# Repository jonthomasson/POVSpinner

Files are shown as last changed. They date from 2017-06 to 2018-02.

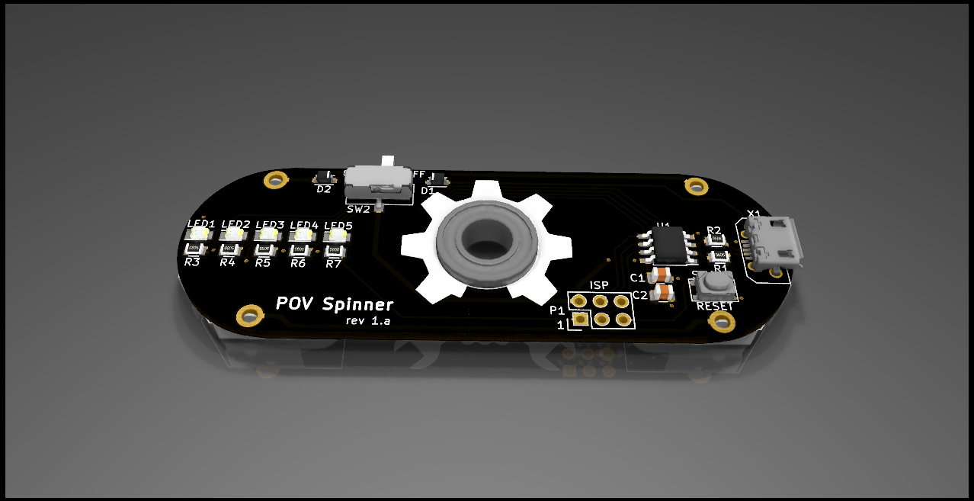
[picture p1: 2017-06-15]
rev1.f/POVSpinner_rtfront.png

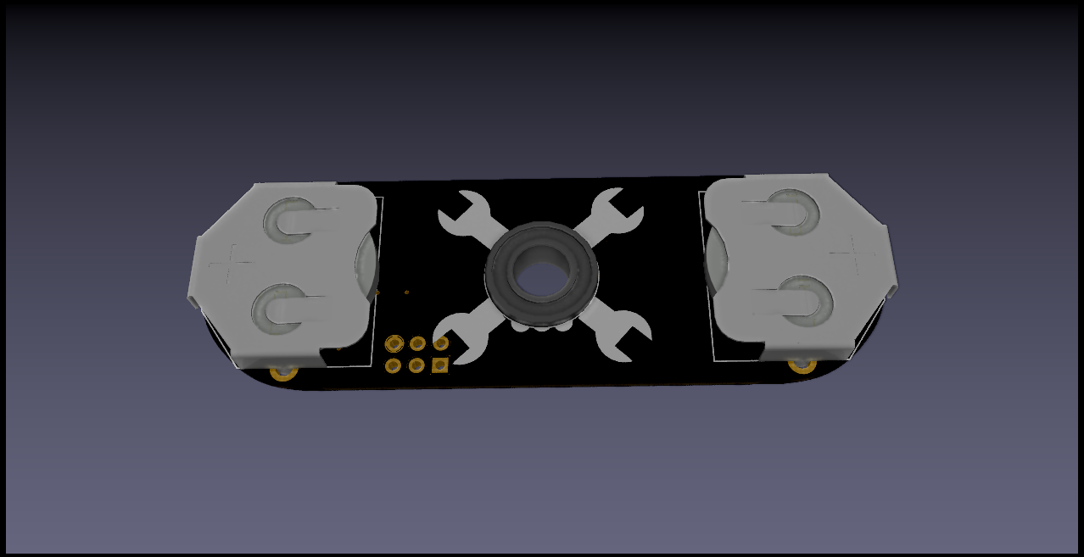
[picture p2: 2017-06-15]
rev1.f/POVSpinner_rtback.png

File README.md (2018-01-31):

# POVSpinner
A simple POV (persistence of vision) fidget spinner. Made with an AtTiny85, 5 LED's, and 2 CR2032 batteries.

A few weeks ago a family member introduced me to the world of fidget spinners. At first I thought they were kinda silly, but after trying one, I started to see their appeal. It hit me that these would be really fun to build a POV (persistence of vision) display around. This project is a culmination of that idea. You can see the finished product in action here: https://www.youtube.com/watch?v=1BgokUmG97M 

Although the most popular fidget spinners seem to be the ones with 3 sides, for this project I decided to go with a 2 sided design. A 2 sided design would enable me to use 2 cr2032 batteries wired in parallel for power, one on either side of the spinner. This would help to balance out the spinner nicely as well as provide enough current to power a small micro and the leds. For the microcontroller, I went with the AtTiny85, since it had a small footprint, a wide operating voltage, and fairly low current draw. I'm using the trinket bootloader to load sketches into the board via the usb plug.

In my original design, I used the popular 608 size bearing. This by far was the bearing of choice it seemed for most fidget spinners. I found though that using this size, left almost no clearance on the sides of the board for traces running to the leds. Ultimately I decided to go instead with the R188 size bearing since, measuring only 12.7mm diameter, it gave me far more clearance to route traces around. I also was able to leave enough clearance around this bearing to hopefully add a cap to make spinning a little easier.

Finally, the ultimate goal of this project was to make something that could inspire fun and learning in this new generation of kids obsessed with fidget spinners. I did this through the use of a simple design, that is both low cost and easy to assemble. This project can be constructed in its entirety in a one off project for as little as $15 total, including the bearings and pcb. All of the components are within the range of anyone to solder. And the schematic and design are easy for anyone to understand.
![enter image description here](https://lh3.googleusercontent.com/DhNOqLcnItDuo_4iJxkey9anFaUFrb0ddoZT6aBiR9evClm_AYBNzVEmYPulBlhxkZ5F0HzZf8USn-Oaba-tvRUW2f26RHXr0ZZY7M68wkTW4eBEowTWm1YilmIVfi8iHBQ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)

![enter image description here](https://lh3.googleusercontent.com/bpmZXRshKWY_OdYD_Kt2YicKdZAlTvVXNBgJA6td2XHRJgiZ3ofWQoVn10eOdQVJL2B-P29Dyr7ATuvkN6joMWVmaqQKLKum0x6HNuumbUMTG-wt7oL7T_7EQA7VCcBzKxE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)

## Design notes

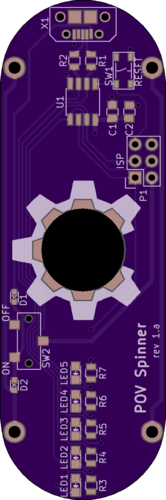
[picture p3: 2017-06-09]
rev1.f/POVSpinner_board.png

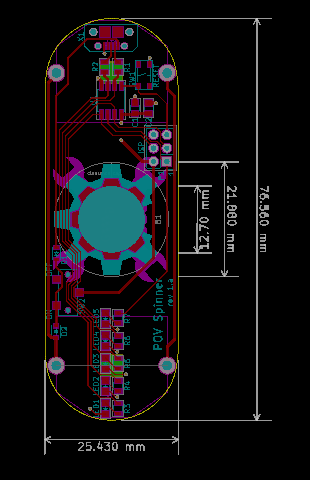
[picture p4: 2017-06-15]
rev1.f/board_dimensions.PNG

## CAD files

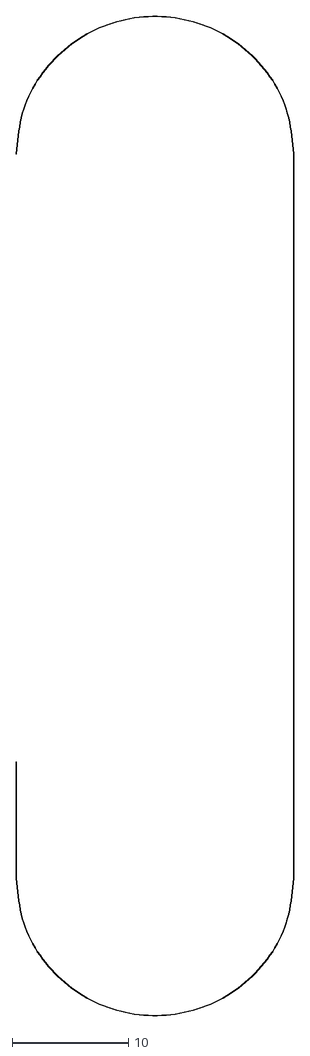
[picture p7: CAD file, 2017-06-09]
rev1.b/board_outline/#outline3a.dxf
23.9 x 86.0

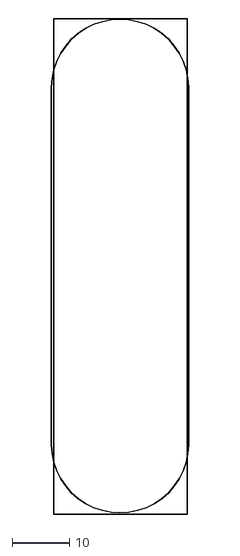
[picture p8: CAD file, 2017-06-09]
rev1.c/board_outline/outline1.dxf
23.9 x 87.0

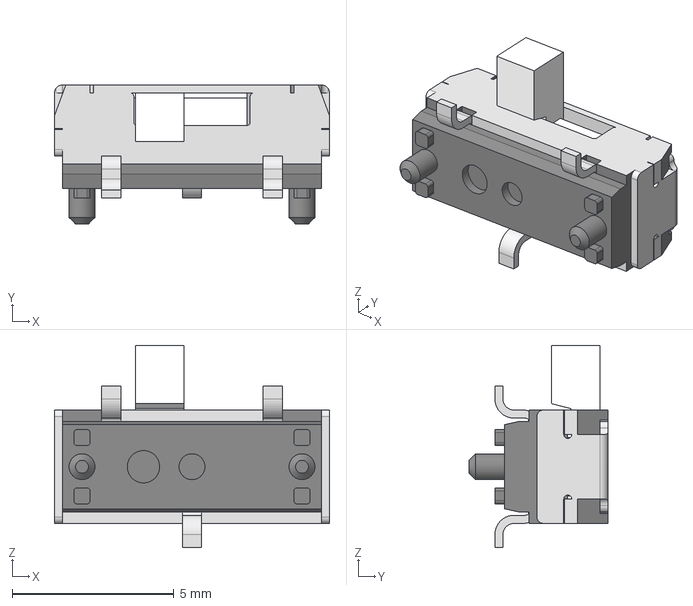
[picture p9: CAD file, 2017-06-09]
rev1.f/3dmodels/CL-SB-12B-11T.stp
8.50 x 4.30 x 6.25 mm
_12B-11_c
_2Side setting_s

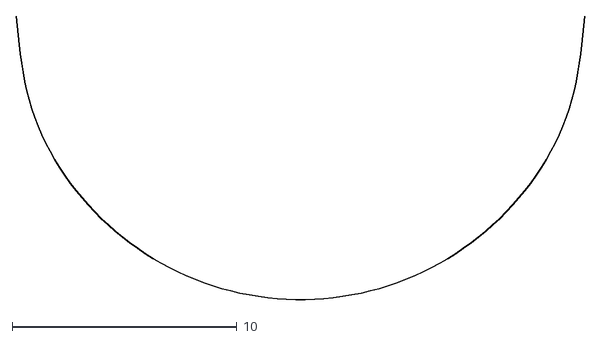
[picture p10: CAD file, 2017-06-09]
rev1.f/board_outline/outline_bottom.dxf
25.3 x 12.6

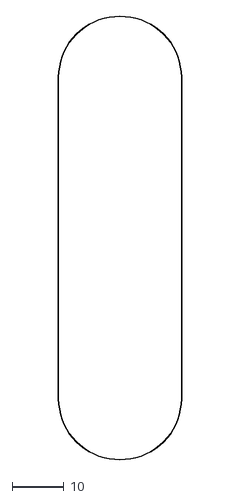
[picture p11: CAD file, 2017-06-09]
rev1.b/board_outline/outline2a.dxf
23.9 x 86.1

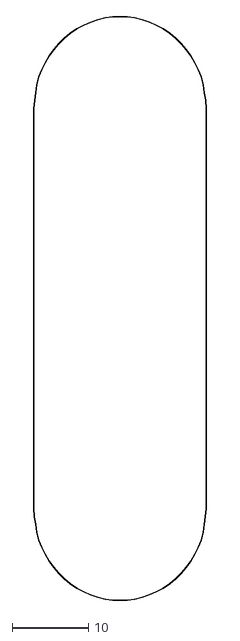
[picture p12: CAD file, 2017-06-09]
rev1.c/board_outline/outline4a.dxf
22.7 x 76.9

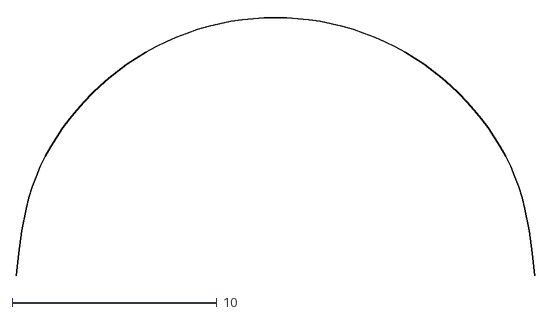
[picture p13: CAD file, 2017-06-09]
rev1.f/board_outline/outlinerevd_top.dxf
25.3 x 12.7

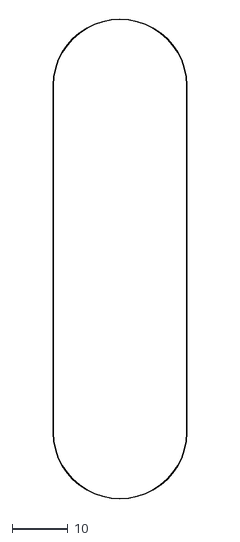
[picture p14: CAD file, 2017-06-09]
rev1.b/board_outline/outline2.dxf
23.9 x 87.0

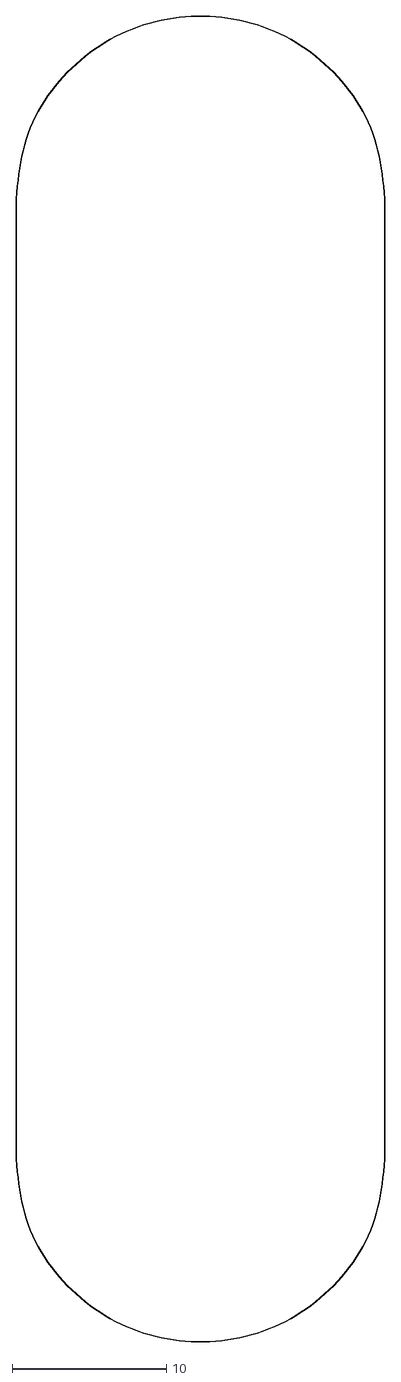
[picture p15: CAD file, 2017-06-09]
rev1.c/board_outline/outline3a.dxf
23.9 x 86.0

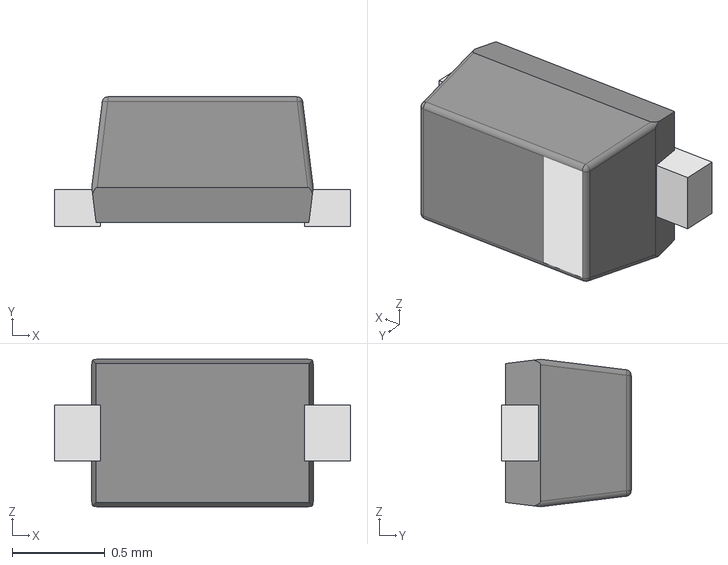
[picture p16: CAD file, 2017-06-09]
rev1.f/3dmodels/Diodes_SOD_523.step
1.60 x 0.7 x 0.798 mm

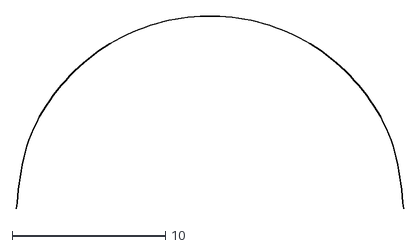
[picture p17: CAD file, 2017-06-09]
rev1.f/board_outline/outline_top.dxf
25.3 x 12.6

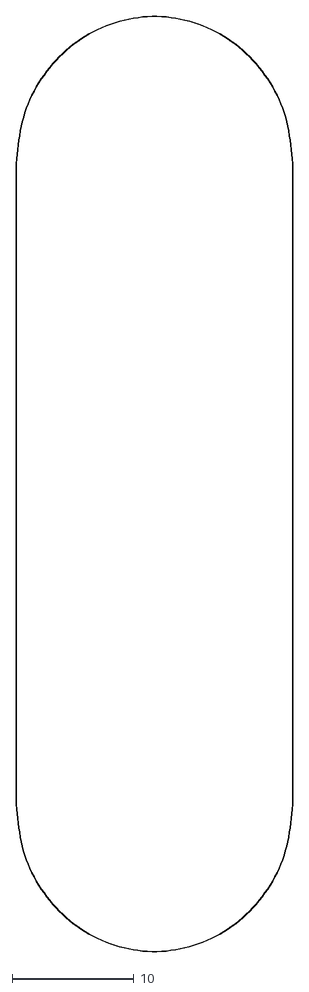
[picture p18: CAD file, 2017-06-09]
rev1.b/board_outline/outline4a.dxf
22.7 x 76.8

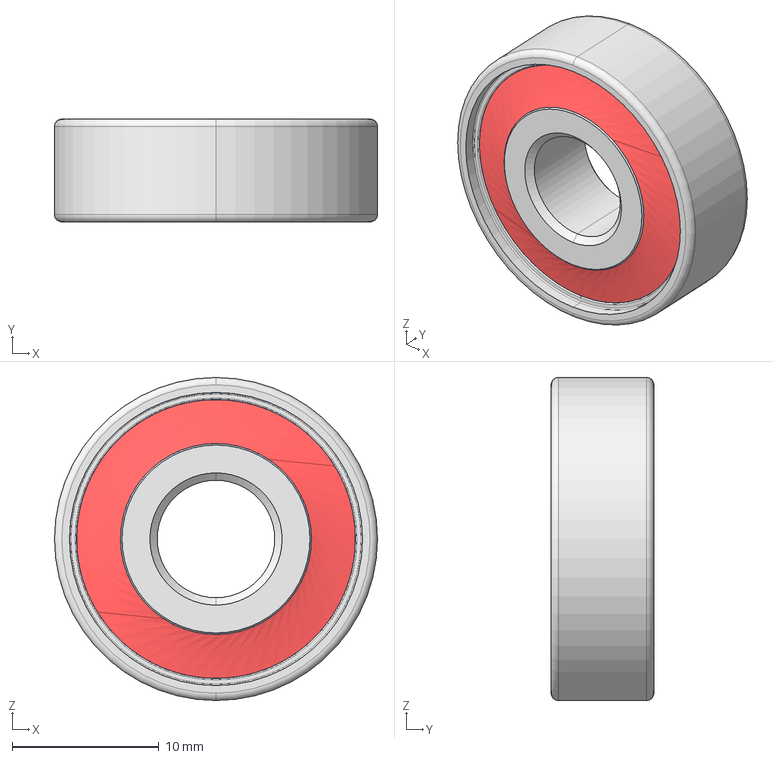
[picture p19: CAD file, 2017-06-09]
rev1.f/3dmodels/608_Bearing.step
22.0 x 7.00 x 22.0 mm

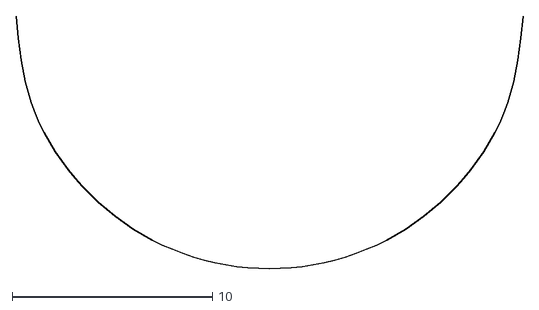
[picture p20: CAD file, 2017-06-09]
rev1.f/board_outline/outlinerevd1a.dxf
25.3 x 12.7

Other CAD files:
rev1.c/board_outline/outline5b.dxf
rev1.f/3dmodels/Bearings_R188.step
rev1.c/board_outline/#outline5a.dxf
rev1.c/board_outline/outline6a.dxf
rev1.c/board_outline/outline6ab.dxf
rev1.c/board_outline/outline6abc.dxf
rev1.c/board_outline/outline6b.dxf
rev1.f/3dmodels/10118194c.stp
rev1.f/3dmodels/BK-888.step
rev1.f/3dmodels/Battery_Holder_MPD_BS_3.step
rev1.f/3dmodels/CL-SB-12B-01T.step
rev1.f/3dmodels/PTS810.stp

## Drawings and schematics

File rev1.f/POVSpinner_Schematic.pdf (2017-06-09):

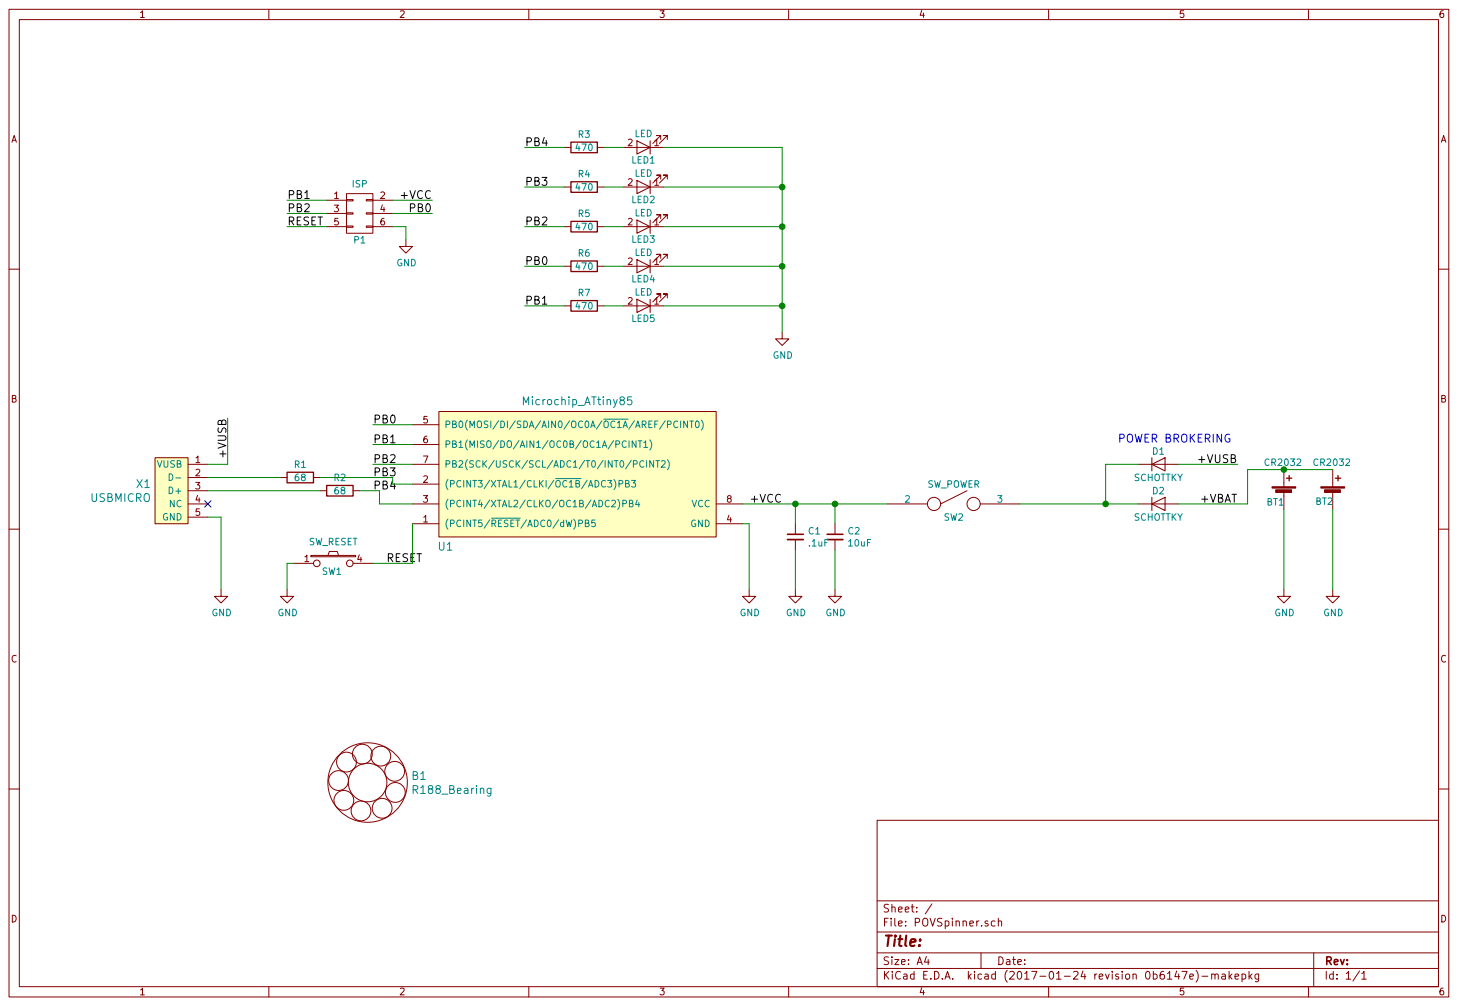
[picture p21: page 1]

File: POVSpinner.sch Sheet: /
Id: 1/1 Title:

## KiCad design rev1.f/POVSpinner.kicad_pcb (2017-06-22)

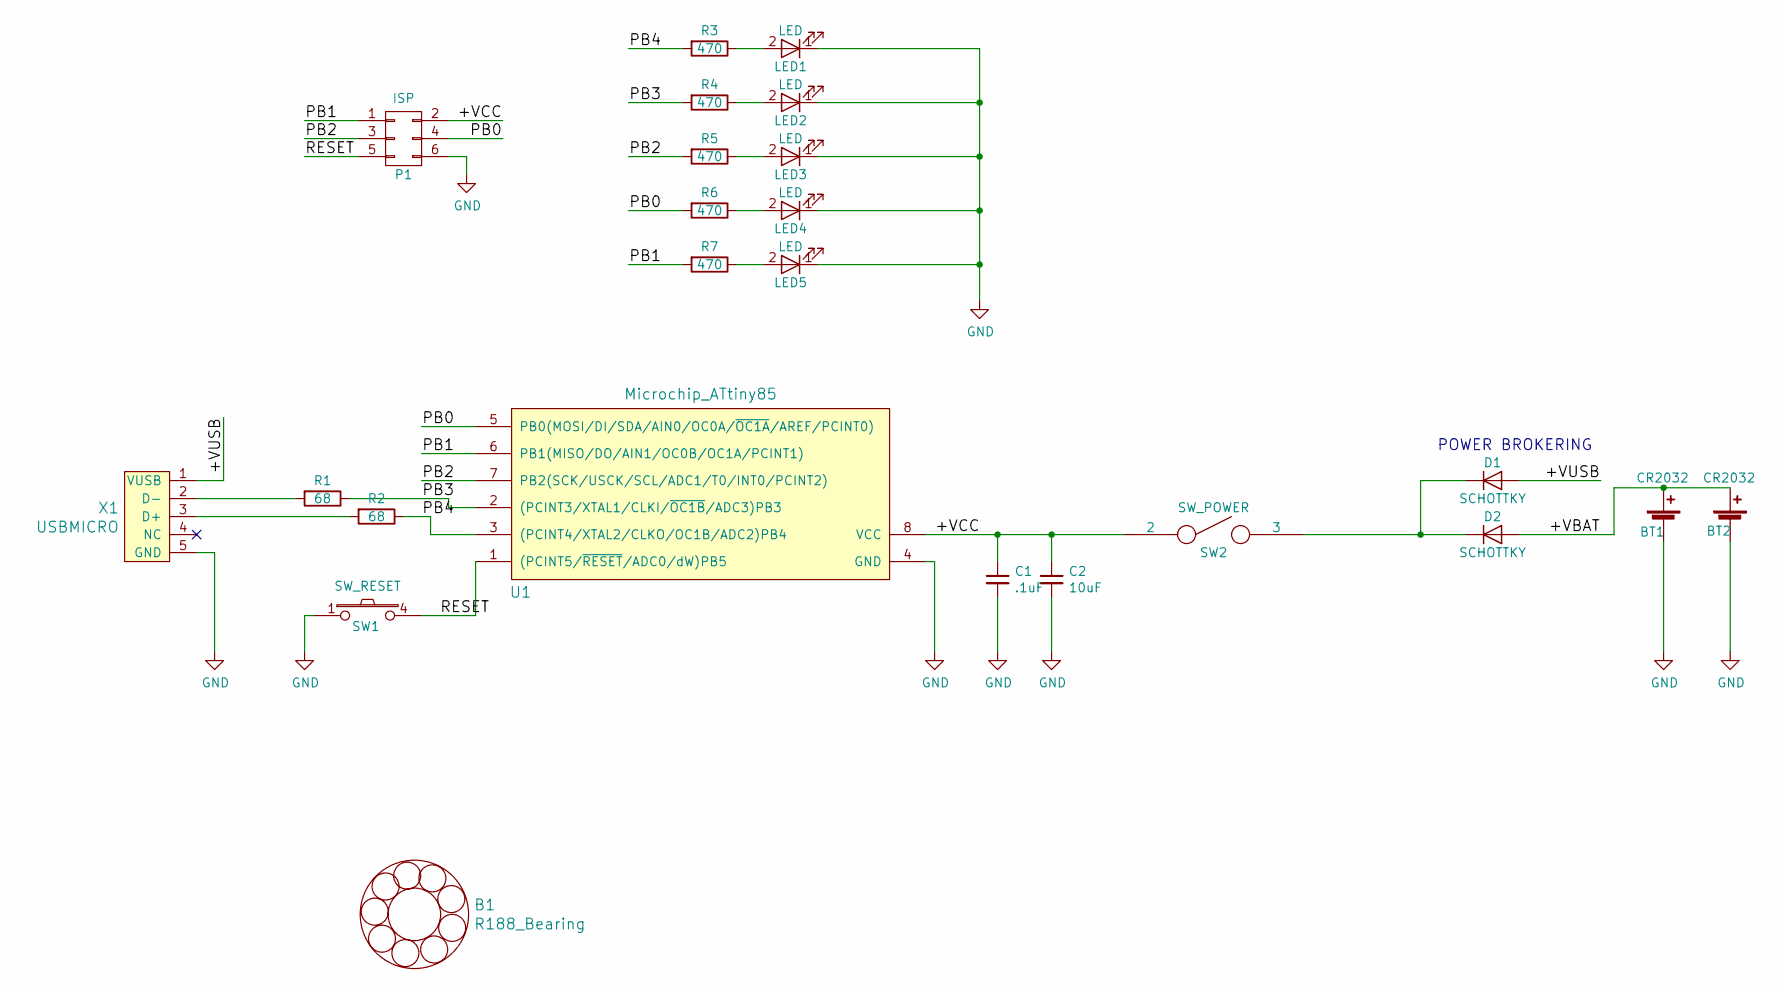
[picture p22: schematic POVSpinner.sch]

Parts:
B1: R188_Bearing; Bearings_R188
BT1, BT2: CR2032; BatteryHolder_MPD_BK_888
C1: .1uF; C_0805
C2: 10uF; C_0805
D1, D2: SCHOTTKY; SOD-323
LED1, LED2, LED3, LED4, LED5: LED; LED_0805
P1: ISP
R1, R2: 68; R_0805
R3, R4, R5, R6, R7: 470; R_0805
SW1: SW_RESET; SWITCH_PTS810
SW2: SW_POWER; SWITCH_CL_SB_12B
U1: Microchip_ATtiny85; SOIJ-8_5.3x5.3mm_Pitch1.27mm
X1: USBMICRO; MICRO_USB_10118194

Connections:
/+VBAT: BT1.1 (+), BT2.1 (+), D2.2 (A)
/+VCC: C1.1, C2.1, P1.2, SW2.2, U1.8 (VCC)
/+VUSB: D1.2 (A), X1.1 (VUSB)
/PB0: P1.4, R6.2, U1.5 (PB0(MOSI/DI/SDA/AIN0/OC0A/~OC1A~/AREF/P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)
/PB1: P1.1, R7.2, U1.6 (PB1(MISO/DO/AIN1/OC0B/OC1A/PCINT1))
/PB2: P1.3, R5.2, U1.7 (PB2(SCK/USCK/SCL/ADC1/T0/INT0/PCINT2))
/PB3: R1.1, R4.2, U1.2 ((PCINT3/XTAL1/CLKI/~OC1B~/ADC3)PB3)
/PB4: R2.1, R3.2, U1.3 ((PCINT4/XTAL2/CLKO/OC1B/ADC2)PB4)
/RESET: P1.5, SW1.4, U1.1 ((PCINT5/~RESET~/ADC0/dW)PB5)
GND: BT1.2 (-), BT2.2 (-), C1.2, C2.2, LED1.1 (K), LED2.1 (K), LED3.1 (K), LED4.1 (K), LED5.1 (K), P1.6, SW1.1, U1.4 (GND), X1.5 (GND)
unnamed: D1.1 (K), D2.1 (K), SW2.3
unnamed: LED1.2 (A), R3.1
unnamed: LED2.2 (A), R4.1
unnamed: LED3.2 (A), R5.1
unnamed: LED4.2 (A), R6.1
unnamed: LED5.2 (A), R7.1
unnamed: R1.2, X1.2 (D-)
unnamed: R2.2, X1.3 (D+)

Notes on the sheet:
POWER BROKERING

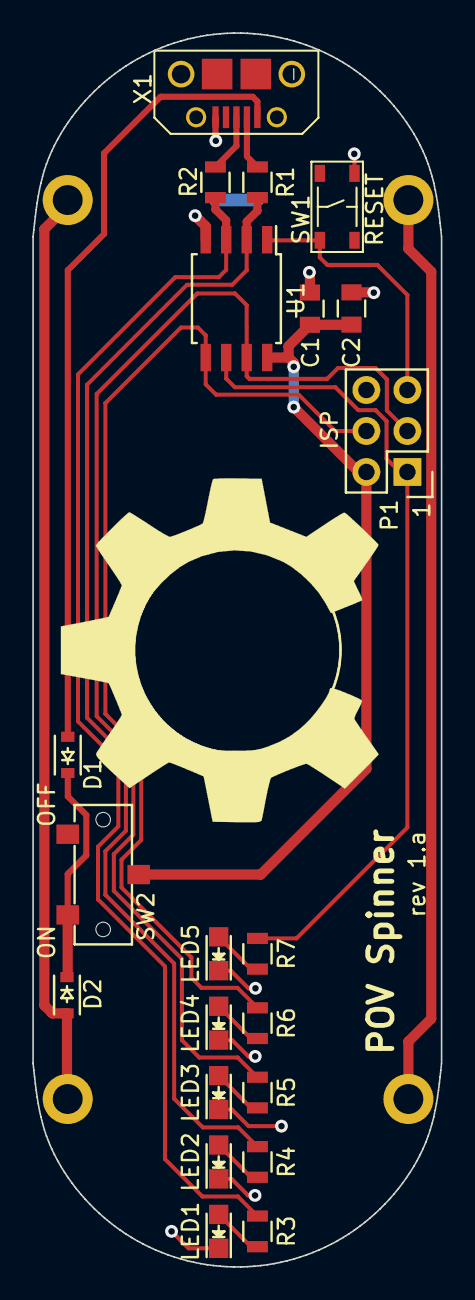
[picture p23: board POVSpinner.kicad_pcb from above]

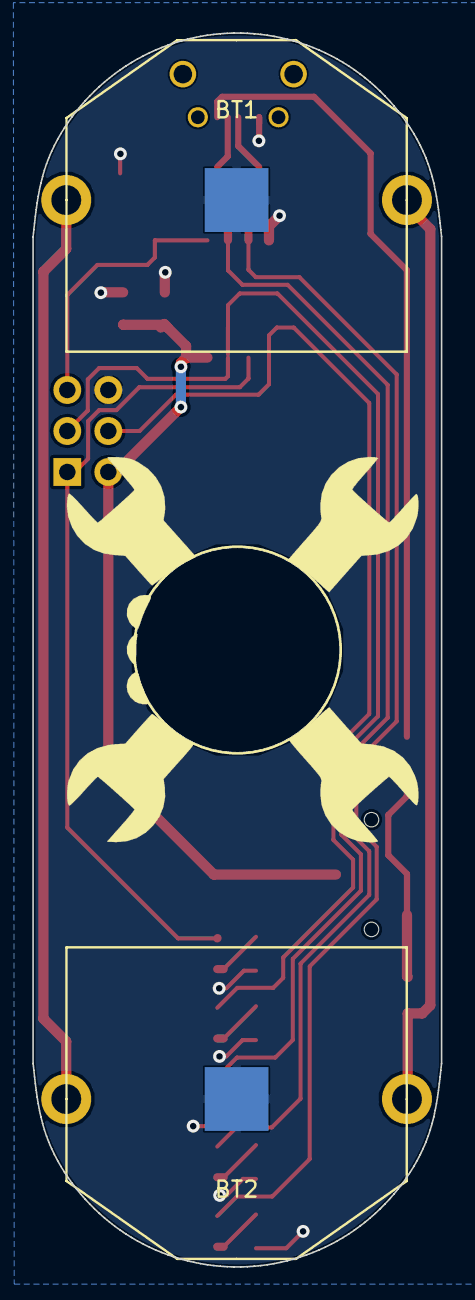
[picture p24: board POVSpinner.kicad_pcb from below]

Board: 2 copper layers, 25.3 x 76.4 mm, 24 parts (2 on the bottom side), 18 nets.

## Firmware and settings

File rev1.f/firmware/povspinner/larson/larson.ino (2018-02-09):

      /*
  Blink
  Turns on an LED on for one second, then off for one second, repeatedly.
 
  This example code is in the public domain.

  To upload to your Gemma or Trinket:
  1) Select the proper board from the Tools->Board Menu
  2) Select USBtinyISP from the Tools->Programmer
  3) Plug in the Gemma/Trinket, make sure you see the green LED lit
  4) For windows, install the USBtiny drivers
  5) Press the button on the Gemma/Trinket - verify you see
     the red LED pulse. This means it is ready to receive data
  6) Click the upload button above within 10 seconds
*/
 

int LED1 = 4;
int LED2 = 3;
int LED3 = 2;
int LED4 = 0;
int LED5 = 1;
// the setup routine runs once when you press reset:
void setup() {
  // initialize the digital pin as an output.
  pinMode(LED1, OUTPUT);
  pinMode(LED2, OUTPUT);
  pinMode(LED3, OUTPUT);
  pinMode(LED4, OUTPUT);
  pinMode(LED5, OUTPUT);

}

// the loop routine runs over and over again forever:
void loop() {
    digitalWrite(LED1, HIGH); 
    delay(50);
    digitalWrite(LED1, LOW);
    digitalWrite(LED2, HIGH); 
    delay(50);
    digitalWrite(LED2, LOW);
    digitalWrite(LED3, HIGH); 
    delay(50);
    digitalWrite(LED3, LOW);
    digitalWrite(LED4, HIGH); 
    delay(50);
    digitalWrite(LED4, LOW);
    digitalWrite(LED5, HIGH); 
    delay(50);
    digitalWrite(LED5, LOW);
    digitalWrite(LED4, HIGH); 
    delay(50);
    digitalWrite(LED4, LOW);
    digitalWrite(LED3, HIGH); 
    delay(50);
    digitalWrite(LED3, LOW);
    digitalWrite(LED2, HIGH); 
    delay(50);
    digitalWrite(LED2, LOW);
    
}
    

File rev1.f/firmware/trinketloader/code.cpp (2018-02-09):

#include "optiLoader.h"

/*
 * Bootload images.
 * These are the intel Hex files produced by the optiboot makefile,
 * with a small amount of automatic editing to turn them into C strings,
 * and a header attched to identify them
 */

extern image_t *images[];
extern uint8_t NUMIMAGES;

/*
 * readSignature
 * read the bottom two signature bytes (if possible) and return them
 * Note that the highest signature byte is the same over all AVRs so we skip it
 */

uint16_t readSignature (void)
{
  SPI.setClockDivider(CLOCKSPEED_FUSES); 
    
  uint16_t target_type = 0;
  Serial.print("\nReading signature:");
  
  target_type = spi_transaction(0x30, 0x00, 0x01, 0x00);
  target_type <<= 8;
  target_type |= spi_transaction(0x30, 0x00, 0x02, 0x00);
  
  Serial.println(target_type, HEX);
  if (target_type == 0 || target_type == 0xFFFF) {
    if (target_type == 0) {
      Serial.println("  (no target attached?)");
    }
  }
  return target_type;
}

/*
 * findImage
 *
 * given 'signature' loaded with the relevant part of the device signature,
 * search the hex images that we have programmed in flash, looking for one
 * that matches.
 */
image_t *findImage (uint16_t signature)
{
  image_t *ip;
  Serial.println("Searching for image...");

  for (byte i=0; i < NUMIMAGES; i++) {
    ip = images[i];

    if (ip && (pgm_read_word(&ip->image_chipsig) == signature)) {
	Serial.print("  Found \"");
	flashprint(&ip->image_name[0]);
	Serial.print("\" for ");
	flashprint(&ip->image_chipname[0]);
	Serial.println();

	return ip;
    }
  }
  Serial.println(" Not Found");
  return 0;
}

/*
 * programmingFuses
 * Program the fuse/lock bits
 */
boolean programFuses (const byte *fuses)
{
  SPI.setClockDivider(CLOCKSPEED_FUSES); 
    
  byte f;
  Serial.print("\nSetting fuses");

  f = pgm_read_byte(&fuses[FUSE_PROT]);
  if (f) {
    Serial.print("\n  Set Lock Fuse to: ");
    Serial.print(f, HEX);
    Serial.print(" -> ");
    Serial.print(spi_transaction(0xAC, 0xE0, 0x00, f), HEX);
  }
  f = pgm_read_byte(&fuses[FUSE_LOW]);
  if (f) {
    Serial.print("  Set Low Fuse to: ");
    Serial.print(f, HEX);
    Serial.print(" -> ");
    Serial.print(spi_transaction(0xAC, 0xA0, 0x00, f), HEX);
  }
  f = pgm_read_byte(&fuses[FUSE_HIGH]);
  if (f) {
    Serial.print("  Set High Fuse to: ");
    Serial.print(f, HEX);
    Serial.print(" -> ");
    Serial.print(spi_transaction(0xAC, 0xA8, 0x00, f), HEX);
  }
  f = pgm_read_byte(&fuses[FUSE_EXT]);
  if (f) {
    Serial.print("  Set Ext Fuse to: ");
    Serial.print(f, HEX);
    Serial.print(" -> ");
    Serial.print(spi_transaction(0xAC, 0xA4, 0x00, f), HEX);
  }
  Serial.println();
  return true;			/* */
}

/*
 * verifyFuses
 * Verifies a fuse set
 */
boolean verifyFuses (const byte *fuses, const byte *fusemask)
{
  SPI.setClockDivider(CLOCKSPEED_FUSES); 
  byte f;
  Serial.println(F("Verifying fuses..."));
  f = pgm_read_byte(&fuses[FUSE_PROT]);
  if (f) {
    uint8_t readfuse = spi_transaction(0x58, 0x00, 0x00, 0x00);  // lock fuse
    readfuse &= pgm_read_byte(&fusemask[FUSE_PROT]);
    Serial.print(F("\tLock Fuse: ")); Serial.print(f, HEX);  Serial.print(" is "); Serial.println(readfuse, HEX);
    if (readfuse != f) 
      return false;
  }
  f = pgm_read_byte(&fuses[FUSE_LOW]);
  if (f) {
    uint8_t readfuse = spi_transaction(0x50, 0x00, 0x00, 0x00);  // low fuse
    Serial.print(F("\tLow Fuse: 0x"));  Serial.print(f, HEX); Serial.print(" is 0x"); Serial.println(readfuse, HEX);
    readfuse &= pgm_read_byte(&fusemask[FUSE_LOW]);
    if (readfuse != f) 
      return false;
  }
  f = pgm_read_byte(&fuses[FUSE_HIGH]);
  if (f) {
    uint8_t readfuse = spi_transaction(0x58, 0x08, 0x00, 0x00);  // high fuse
    readfuse &= pgm_read_byte(&fusemask[FUSE_HIGH]);
    Serial.print(F("\tHigh Fuse: 0x"));  Serial.print(f, HEX); Serial.print(" is 0x");  Serial.println(readfuse, HEX);
    if (readfuse != f) 
      return false;
  }
  f = pgm_read_byte(&fuses[FUSE_EXT]);
  if (f) {
    uint8_t readfuse = spi_transaction(0x50, 0x08, 0x00, 0x00);  // ext fuse
    readfuse &= pgm_read_byte(&fusemask[FUSE_EXT]);
    Serial.print("\tExt Fuse: 0x"); Serial.print(f, HEX); Serial.print(" is 0x"); Serial.println(readfuse, HEX);
    if (readfuse != f) 
      return false;
  }
  Serial.println();
  return true;			/* */
}



/*
 * readImagePage
 *
 * Read a page of intel hex image from a string in pgm memory.
*/

// Returns number of bytes decoded
byte * readImagePage (byte *hextext, uint16_t pageaddr, uint8_t pagesize, byte *page)
{
  
  boolean firstline = true;
  uint16_t len;
  uint8_t page_idx = 0;
  byte *beginning = hextext;
  
  byte b, cksum = 0;

  //Serial.print("page size = "); Serial.println(pagesize, DEC);

  // 'empty' the page by filling it with 0xFF's
  for (uint8_t i=0; i<pagesize; i++)
    page[i] = 0xFF;

  while (1) {
    uint16_t lineaddr;
    
      // read one line!
    if (pgm_read_byte(hextext++) != ':') {
      error("No colon?");
      break;
    }
    // Read the byte count into 'len'
    len = hexton(pgm_read_byte(hextext++));
    len = (len<<4) + hexton(pgm_read_byte(hextext++));
    cksum = len;
    
    // read high address byte
    b = hexton(pgm_read_byte(hextext++));  
    b = (b<<4) + hexton(pgm_read_byte(hextext++));
    cksum += b;
    lineaddr = b;
    
    // read low address byte
    b = hexton(pgm_read_byte(hextext++)); 
    b = (b<<4) + hexton(pgm_read_byte(hextext++));
    cksum += b;
    lineaddr = (lineaddr << 8) + b;
    
    if (lineaddr >= (pageaddr + pagesize)) {
      return beginning;
    }

    b = hexton(pgm_read_byte(hextext++)); // record type 
    b = (b<<4) + hexton(pgm_read_byte(hextext++));
    cksum += b;
    //Serial.print("Record type "); Serial.println(b, HEX);
    if (b == 0x1) { 
     // end record!
     break;
    } 
#if VERBOSE
    Serial.print("\nLine address =  0x"); Serial.println(lineaddr, HEX);      
    Serial.print("Page address =  0x"); Serial.println(pageaddr, HEX);      
#endif
    for (byte i=0; i < len; i++) {
      // read 'n' bytes
      b = hexton(pgm_read_byte(hextext++));
      b = (b<<4) + hexton(pgm_read_byte(hextext++));
      
      cksum += b;
#if VERBOSE
      Serial.print(b, HEX);
      Serial.write(' ');
#endif

      page[page_idx] = b;
      page_idx++;

      if (page_idx > pagesize) {
          error("Too much code");
	  break;
      }
    }
    b = hexton(pgm_read_byte(hextext++));  // chxsum
    b = (b<<4) + hexton(pgm_read_byte(hextext++));
    cksum += b;
    if (cksum != 0) {
      error("Bad checksum: ");
      Serial.print(cksum, HEX);
    }
    if (pgm_read_byte(hextext++) != '\n') {
      error("No end of line");
      break;
    }
#if VERBOSE
    Serial.println();
    Serial.println(page_idx, DEC);
#endif
    if (page_idx == pagesize) 
      break;
  }
#if VERBOSE
  Serial.print("\n  Total bytes read: ");
  Serial.println(page_idx, DEC);
#endif
  return hextext;
}
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

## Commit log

2017-06-15 added larger blocking diodes and fixed the isp connector pinout
    [10118194c.stp, 608_Bearing.step, BK-888.step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]
2017-06-22 added new 5.3mm soic 8 footprint for AtTiny85
    [POVSpinner.kicad_pcb, POVSpinner.sch]
